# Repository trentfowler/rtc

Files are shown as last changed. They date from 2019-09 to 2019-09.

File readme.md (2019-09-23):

# Real time clock drop-in circuit block/pcb reference

**Description:** KiCad schematic and reference pcb layout for a real time clock that uses the DS1302 rtc chip.

DS1302 - https://datasheets.maximintegrated.com/en/ds/DS1302.pdf

BOM - https://www.digikey.com/short/p2twq1

schematic

3d

pcb front

pcb back

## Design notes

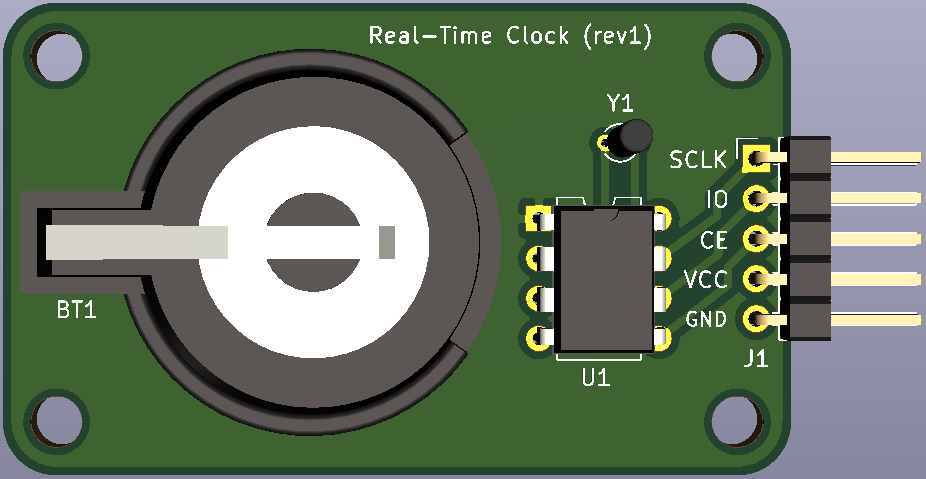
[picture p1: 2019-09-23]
img/rev1/3d_qPBAPDq.png

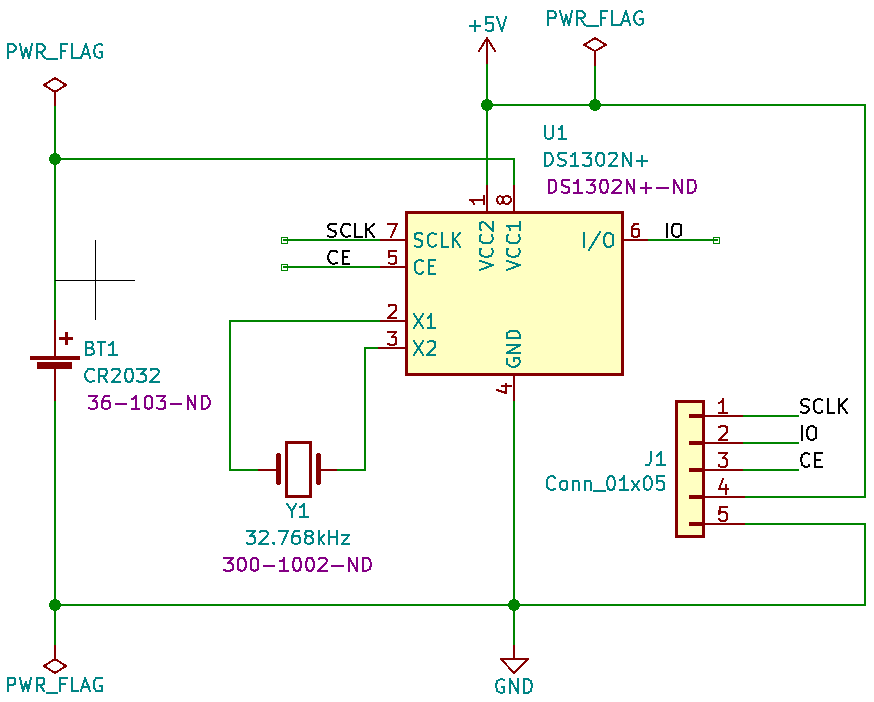
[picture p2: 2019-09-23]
img/rev1/sch_LXBE2bn.png

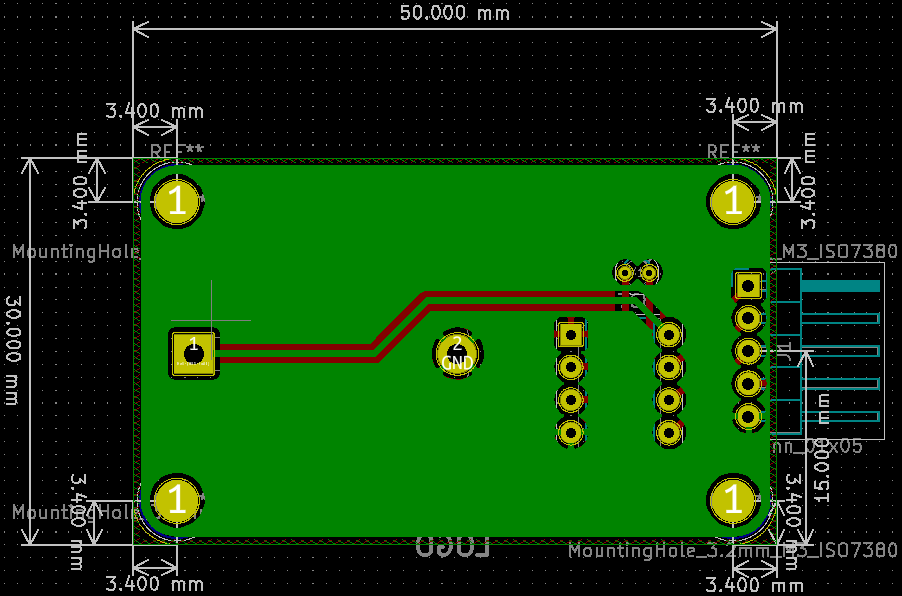
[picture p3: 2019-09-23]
img/rev1/pcb_back_HhG7MJW.png

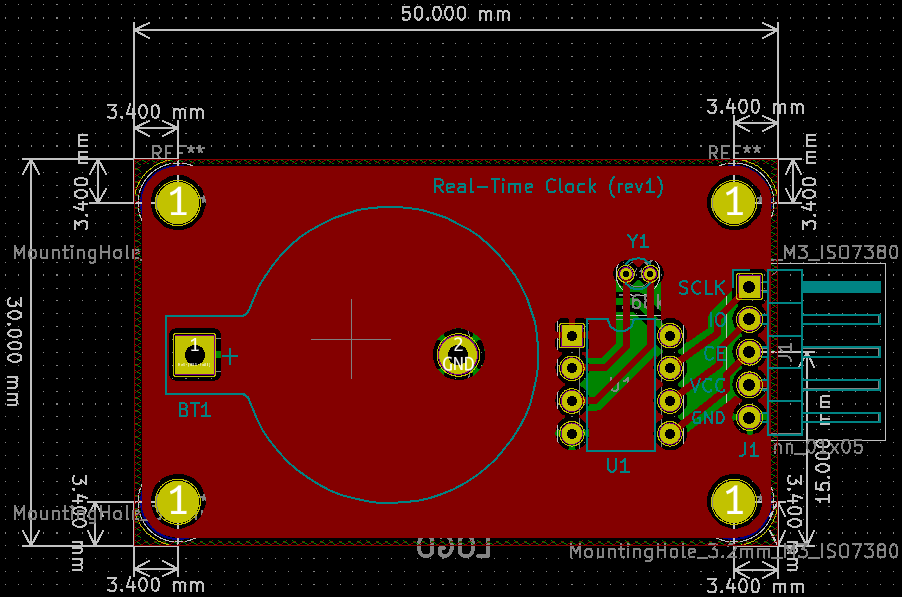
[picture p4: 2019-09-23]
img/rev1/pcb_front_4CxzNEO.png

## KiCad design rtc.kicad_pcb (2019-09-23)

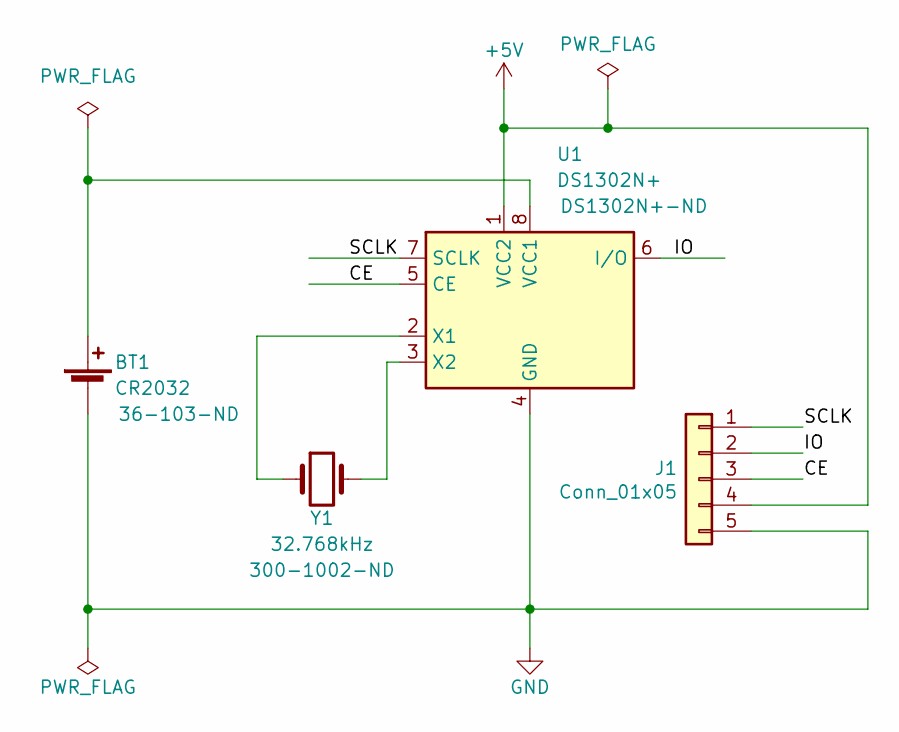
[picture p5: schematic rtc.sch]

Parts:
BT1: CR2032; BatteryHolder_Keystone_103_1x20mm; digikey 36-103-ND
J1: Conn_01x05; PinHeader_1x05_P2.54mm_Horizontal
U1: DS1302N+; DIP-8_W7.62mm; digikey DS1302N+-ND
Y1: 32.768kHz; Crystal_Round_D2.0mm_Vertical; digikey 300-1002-ND

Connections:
+5V: J1.4, U1.1 (VCC2)
/CE: J1.3, U1.5 (CE)
/IO: J1.2, U1.6 (I/O)
/SCLK: J1.1, U1.7 (SCLK)
GND: BT1.2 (-), J1.5, U1.4 (GND)
unnamed: BT1.1 (+), U1.8 (VCC1)
unnamed: U1.2 (X1), Y1.1
unnamed: U1.3 (X2), Y1.2

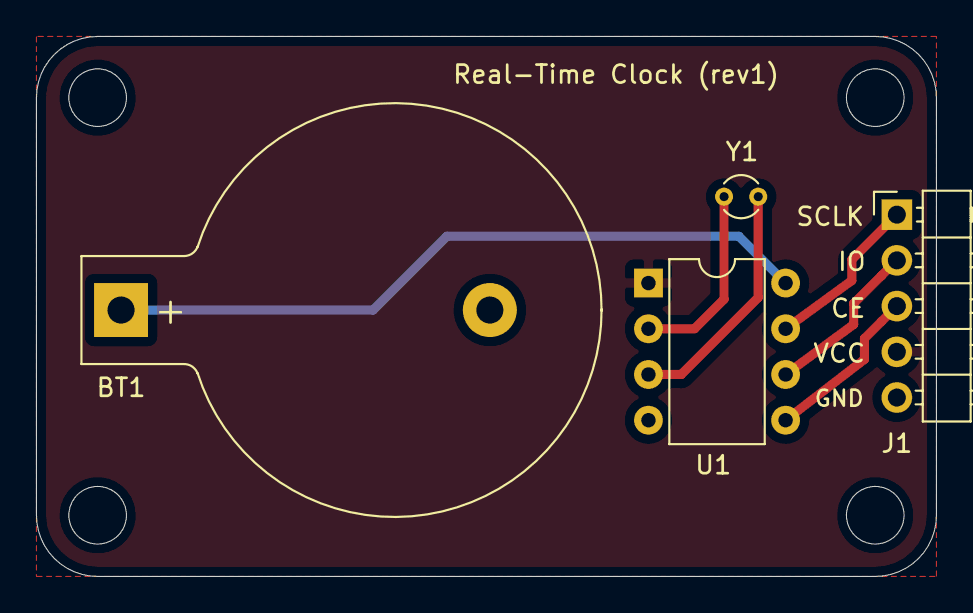
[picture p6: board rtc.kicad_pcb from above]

Board: 2 copper layers, 50.0 x 30.0 mm, 4 parts (0 on the bottom side), 8 nets.

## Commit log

2019-09-21 Initial commit (schematic only)
    [rtc.kicad_pcb, rtc.sch]
2019-09-21 Tweak schematic and add pwr markers. Assign footprints.
    - Generate net list
    [rtc.sch]
2019-09-21 Initial pcb layout and routing. Add readme/imgs.
    - Added design rules for oshpark
    - Added mounting holes and 30x50mm board outline
    [rtc.sch]
2019-09-22 Remove redundant pull-ups per datasheet
    - Capacitors accross crystal removed per datasheet info on oscillator circuit
    [rtc.kicad_pcb, rtc.sch]
2019-09-22 Simplify schematic and update readme
    [rtc.sch]
2019-09-22 Simplify by removing pull-ups and bypass cap per datasheet
    - Re-run traces
    - Update img/readme
    [rtc.kicad_pcb, rtc.sch]
2019-09-22 Remove front copper polygon fill
    - Clean up labels
    [rtc.kicad_pcb]
2019-09-23 Update schematic labels and associate footprints with new digikey component selections
    [rtc.sch]
2019-09-23 Redo pcb layout and traces
    - Restored front copper polygon fill
    [rtc.kicad_pcb]
2019-09-23 Clean up silk screen labels
    [rtc.kicad_pcb]
2019-09-23 Round edgecuts
    - New project footprint library rtc.pretty
    - Added logo to silkscreen
    - Added title/rev to silkscreen
    [rtc.kicad_pcb]
2019-09-23 Fix courtyard drc error on keystone 103 holder
    - fix outline on keystone 103 battery holder and move fixed part into
    rtc.pretty
    [rtc.kicad_pcb, rtc.sch]
2019-09-23 Add digikey bom or cart share to readme
2019-09-23 final rev1 commit with gerbers folder and gerbers.zip
    [rtc-B_Cu.gbr, rtc-B_Mask.gbr, rtc-B_SilkS.gbr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]
